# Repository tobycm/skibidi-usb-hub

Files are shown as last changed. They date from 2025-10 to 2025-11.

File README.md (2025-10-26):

# skibidi usb hub - 7-port usb hub with some ethernet and an audio out jack

me when my ethernet port and audio jack is broken and i need more usb A ports :bonk:

features:
 - 1 USB C port for upstream
 - 2 USB C ports
 - 2 USB A ports
 - 2 100M capable Ethernet ports
 - 1 Audio Jack (maybe both line in and line out)

## Build

JLCPCB Params:
- Stack up: JLC04161H-7628

## Pictures:

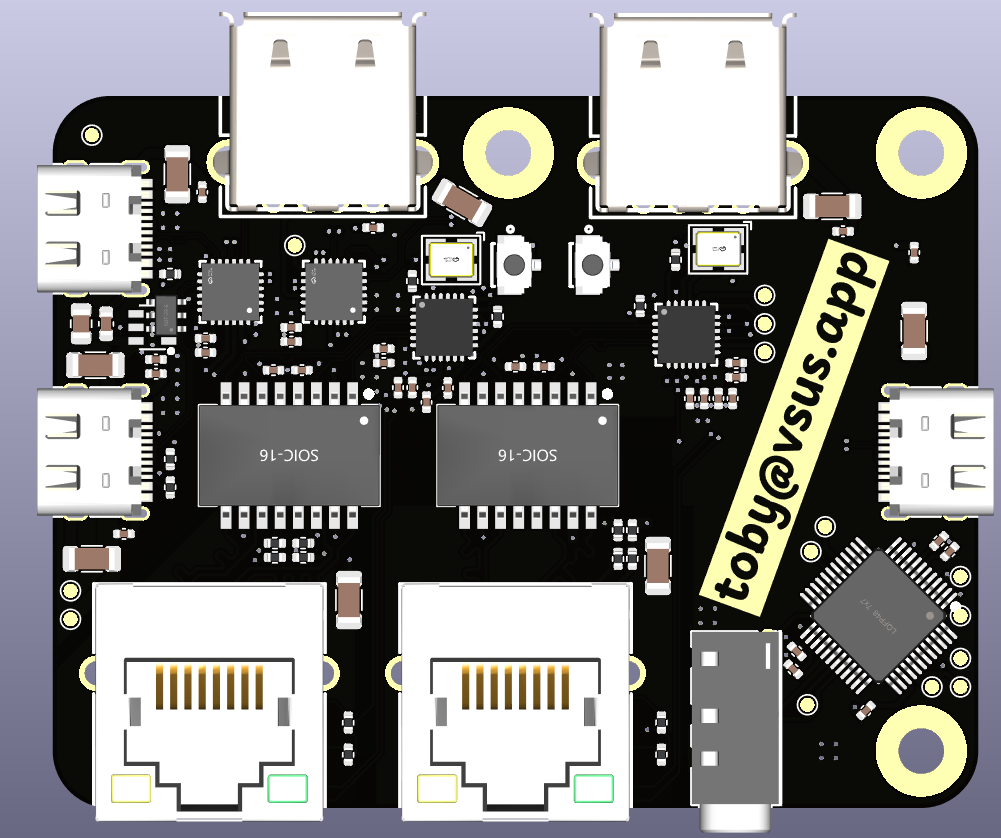
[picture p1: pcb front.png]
pcb front
PCB Front: 

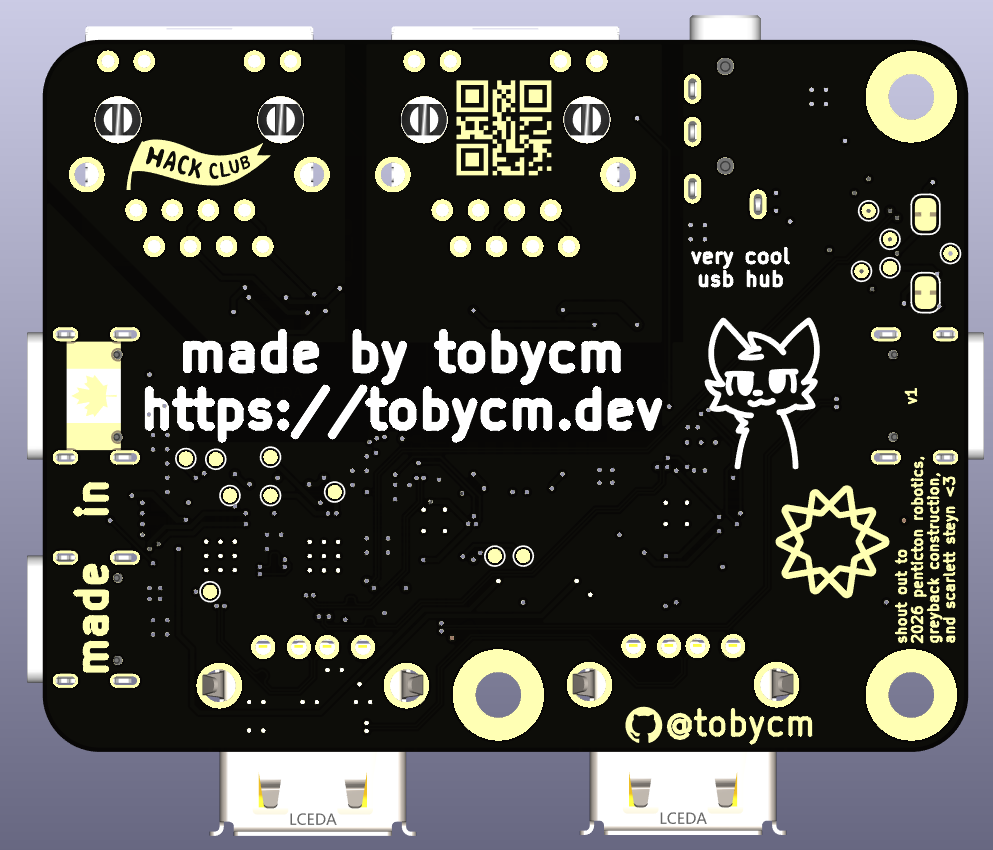
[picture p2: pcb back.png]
pcb back
PCB Back:

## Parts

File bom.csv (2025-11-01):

Qty | Value | LCSC Part #
9 | 100nF | C1525
19 | 1uF | C52923
1 | 10uF | C19702
1 | 47uF | C16780
6 | 100uF | C15008
4 | 10nF | C60133
2 | 1nF | C9196
3 | 56kohm | C25796
2 | 2.49kohm | C25884
2 | 5.1kohm | C25905
8 | 75ohm | C114757
4 | 470ohm | C114877
2 | R-RJ45S08P-C000 | C386764
2 | B3U-1100PM | C6467298
2 | H1102NLT_C20623173 | C20623173
2 | CH334F_C5187527 | C5187527
1 | CH217K | C7462749
3 | GT-USB-7010ASV | C2988369
2 | RTL8152B-VB-CG | C50656
1 | HS-100B | C371351
1 | PJ-320A-4P DIP | C18185602
2 | AF 90° WJDG | C456018
2 | X322516MLB4SI | C13738
 | LCSC | $47.73
 | LCSC Shipping | $20.00
 | PCB | $28.00
 | Stencil | $3.00
 | JLCPCB Shipping | $9.00
 | Shipping customs | $22.69
 | Total | $130.42

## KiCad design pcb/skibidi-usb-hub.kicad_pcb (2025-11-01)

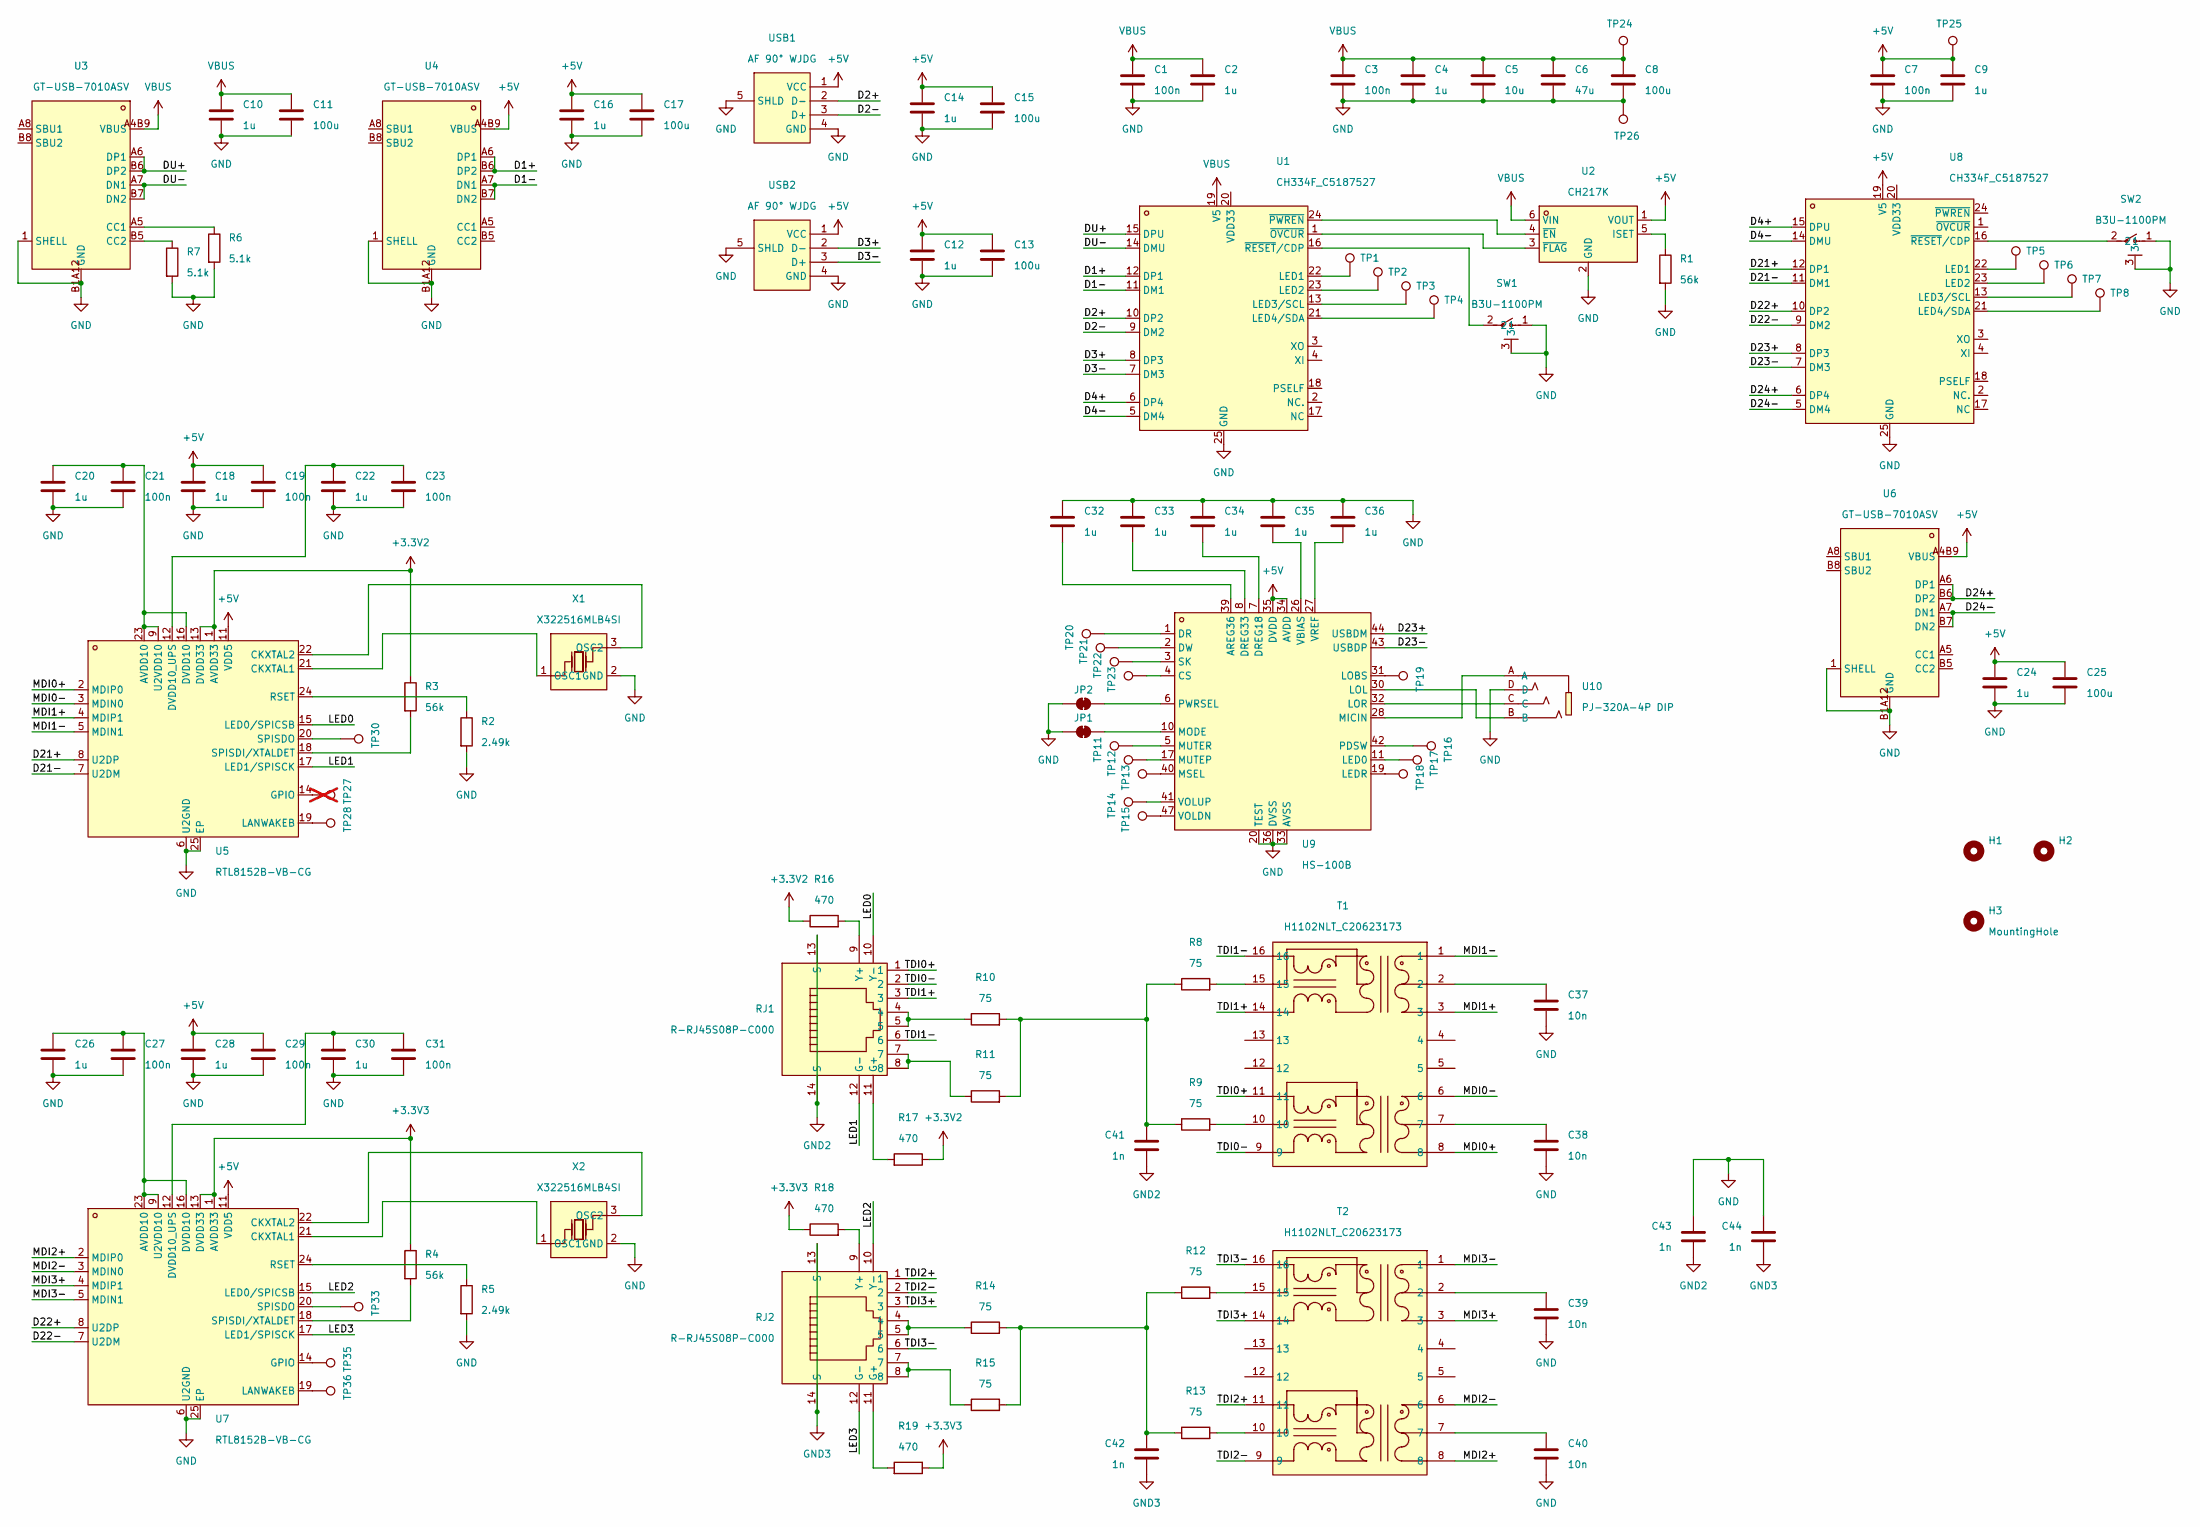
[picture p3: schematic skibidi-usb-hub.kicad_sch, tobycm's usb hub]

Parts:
C1, C3, C7, C19, C21, C23, C27, C29, C31: 100n; C_0402_1005Metric; LCSC Part # C1525
C2, C4, C9, C10, C12, C14, C16, C18, C20, C22, C24, C26, C28, C30, C32, C33, C34, C35, C36: 1u; C_0402_1005Metric; LCSC Part # C52923
C5: 10u; C_0603_1608Metric; LCSC Part # C19702
C6: 47u; C_0805_2012Metric; LCSC Part # C16780
C8, C11, C13, C15, C17, C25: 100u; C_1206_3216Metric; LCSC Part # C15008
C37, C38, C39, C40: 10n; C_0402_1005Metric; LCSC Part # C60133
C41, C42, C43, C44: 1n; C_1206_3216Metric; LCSC Part # C9196
H1, H2, H3: MountingHole; MountingHole_3.2mm_M3_Pad
JP1, JP2: SolderJumper_2_Bridged; SolderJumper-2_P1.3mm_Bridged_RoundedPad1.0x1.5mm
R1, R3, R4: 56k; R_0402_1005Metric; LCSC Part # C25796
R2, R5: 2.49k; R_0402_1005Metric; LCSC Part # C25884
R6, R7: 5.1k; R_0402_1005Metric; LCSC Part # C25905
R8, R9, R10, R11, R12, R13, R14, R15: 75; R_0402_1005Metric; LCSC Part # C114757
R16, R17, R18, R19: 470; R_0402_1005Metric; LCSC Part # C114877
RJ1, RJ2: R-RJ45S08P-C000; RJ45-TH_R-RJ45S08P-C000; LCSC Part C386764
SW1, SW2: B3U-1100PM; SW-SMD_3P-L3.0-W2.5-LS4.0; LCSC Part C6467298
T1, T2: H1102NLT_C20623173; XFMR-SMD_H1102NLT; LCSC Part C20623173
TP1, TP2, TP3, TP4, TP5, TP6, TP7, TP8, TP11, TP12, TP13, TP14, TP15, TP16, TP17, TP18, TP19, TP20, TP21, TP22, TP23, TP24, TP25, TP26, TP28, TP30, TP33, TP35, TP36: TestPoint; TestPoint_Pad_D1.0mm
TP27: TestPoint; TestPoint_Pad_D1.0mm; not fitted
U1, U8: CH334F_C5187527; QFN-24_L4.0-W4.0-P0.50-BL-EP2.8; LCSC Part C5187527
U2: CH217K; SOT-23-6_L2.9-W1.6-P0.95-LS2.8-BL; LCSC Part C7462749
U3, U4, U6: GT-USB-7010ASV; USB-C-SMD_G-SWITCH_GT-USB-7010ASV; LCSC Part C2988369
U5, U7: RTL8152B-VB-CG; QFN-24_L4.0-W4.0-P0.50-BL-EP2.0; LCSC Part C50656
U9: HS-100B; LQFP-48_L7.0-W7.0-P0.50-LS9.0-BL; LCSC Part C371351
U10: PJ-320A-4P DIP; AUDIO-TH_PJ-320A-4P-DIP; LCSC Part C18185602
USB1, USB2: AF 90° WJDG; USB-A-TH_AF-WJDG; LCSC Part C456018
X1, X2: X322516MLB4SI; OSC-SMD_4P-L3.2-W2.5-BL; LCSC Part C13738

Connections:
+3.3V2: R3.1, R16.1, R17.1, U5.1 (AVDD33), U5.10 (AVDD33), U5.13 (DVDD33)
+3.3V3: R4.1, R18.1, R19.1, U7.1 (AVDD33), U7.10 (AVDD33), U7.13 (DVDD33)
+5V: C7.1, C9.1, C12.1, C13.1, C14.1, C15.1, C16.1, C17.1, C18.1, C19.1, C24.1, C25.1, C28.1, C29.1, TP25.1, U2.1 (VOUT), U4.A4B9 (VBUS), U4.B4A9 (VBUS), U5.11 (VDD5), U6.A4B9 (VBUS), U6.B4A9 (VBUS), U7.11 (VDD5), U8.19 (V5), U9.29 (AVDD), U9.34 (AVDD), U9.35 (DVDD), USB1.1 (VCC), USB2.1 (VCC)
/D1+: U1.12 (DP1), U4.A6 (DP1), U4.B6 (DP2)
/D1-: U1.11 (DM1), U4.A7 (DN1), U4.B7 (DN2)
/D2+: U1.10 (DP2), USB1.2 (D-)
/D2-: U1.9 (DM2), USB1.3 (D+)
/D3+: U1.8 (DP3), USB2.2 (D-)
/D3-: U1.7 (DM3), USB2.3 (D+)
/D4+: U1.6 (DP4), U8.15 (DPU)
/D4-: U1.5 (DM4), U8.14 (DMU)
/D21+: U5.8 (U2DP), U8.12 (DP1)
/D21-: U5.7 (U2DM), U8.11 (DM1)
/D22+: U7.8 (U2DP), U8.10 (DP2)
/D22-: U7.7 (U2DM), U8.9 (DM2)
/D23+: U8.8 (DP3), U9.44 (USBDM)
/D23-: U8.7 (DM3), U9.43 (USBDP)
/D24+: U6.A6 (DP1), U6.B6 (DP2), U8.6 (DP4)
/D24-: U6.A7 (DN1), U6.B7 (DN2), U8.5 (DM4)
/DU+: U1.15 (DPU), U3.A6 (DP1), U3.B6 (DP2)
/DU-: U1.14 (DMU), U3.A7 (DN1), U3.B7 (DN2)
/LED0: RJ1.10 (Y-), U5.15 (LED0/SPICSB)
/LED1: RJ1.12 (G-), U5.17 (LED1/SPISCK)
/LED2: RJ2.10 (Y-), U7.15 (LED0/SPICSB)
/LED3: RJ2.12 (G-), U7.17 (LED1/SPISCK)
/MDI0+: T1.8, U5.2 (MDIP0)
/MDI0-: T1.6, U5.3 (MDIN0)
/MDI1+: T1.3, U5.4 (MDIP1)
/MDI1-: T1.1, U5.5 (MDIN1)
/MDI2+: T2.8, U7.2 (MDIP0)
/MDI2-: T2.6, U7.3 (MDIN0)
/MDI3+: T2.3, U7.4 (MDIP1)
/MDI3-: T2.1, U7.5 (MDIN1)
/TDI0+: RJ1.1, T1.11
/TDI0-: RJ1.2, T1.9
/TDI1+: RJ1.3, T1.14
/TDI1-: RJ1.6, T1.16
/TDI2+: RJ2.1, T2.11
/TDI2-: RJ2.2, T2.9
/TDI3+: RJ2.3, T2.14
/TDI3-: RJ2.6, T2.16
GND: C1.2, C2.2, C3.2, C4.2, C5.2, C6.2, C7.2, C8.2, C9.2, C10.2, C11.2, C12.2, C13.2, C14.2, C15.2, C16.2, C17.2, C18.2, C19.2, C20.2, C21.2, C22.2, C23.2, C24.2, C25.2, C26.2, C27.2, C28.2, C29.2, C30.2, C31.2, C32.1, C33.1, C34.1, C35.1, C36.1, C37.2, C38.2, C39.2, C40.2, C43.1, C44.1, JP1.1 (A), JP2.1 (A), R1.2, R2.2, R5.2, R6.2, R7.2, SW1.1, SW1.3, SW2.1, SW2.3, TP26.1, U1.25 (GND), U2.2 (GND), U3.1 (SHELL), U3.2 (SHELL), U3.3 (SHELL), U3.4 (SHELL), U3.A1B12 (GND), U3.B1A12 (GND), U4.1 (SHELL), U4.2 (SHELL), U4.3 (SHELL), U4.4 (SHELL), U4.A1B12 (GND), U4.B1A12 (GND), U5.6 (U2GND), U5.25 (EP), U6.1 (SHELL), U6.2 (SHELL), U6.3 (SHELL), U6.4 (SHELL), U6.A1B12 (GND), U6.B1A12 (GND), U7.6 (U2GND), U7.25 (EP), U8.25 (GND), U9.12 (DVSS), U9.20 (TEST), U9.25 (AVSS), U9.33 (AVSS), U9.36 (DVSS), U10.D, USB1.4 (GND), USB1.5 (SHLD), USB2.4 (GND), USB2.5 (SHLD), X1.2 (GND), X1.4 (GND), X2.2 (GND), X2.4 (GND)
GND2: C41.2, C43.2, RJ1.13 (S), RJ1.14 (S)
GND3: C42.2, C44.2, RJ2.13 (S), RJ2.14 (S)
unnamed: C37.1, T1.2
unnamed: C38.1, T1.7
unnamed: C39.1, T2.2
unnamed: C40.1, T2.7
unnamed: C41.1, R8.1, R9.1, R10.2, R11.2
unnamed: C42.1, R12.1, R13.1, R14.2, R15.2
unnamed: JP1.2 (B), U9.10 (MODE)
unnamed: JP2.2 (B), U9.6 (PWRSEL)
unnamed: R8.2, T1.15
unnamed: R9.2, T1.10
unnamed: R10.1, RJ1.4, RJ1.5
unnamed: R11.1, RJ1.7, RJ1.8
unnamed: R12.2, T2.15
unnamed: R13.2, T2.10
unnamed: R14.1, RJ2.4, RJ2.5
unnamed: R15.1, RJ2.7, RJ2.8
unnamed: R17.2, RJ1.11 (G+)
unnamed: R16.2, RJ1.9 (Y+)
unnamed: R19.2, RJ2.11 (G+)
unnamed: R18.2, RJ2.9 (Y+)
unnamed: TP1.1, U1.22 (LED1)
unnamed: TP2.1, U1.23 (LED2)
unnamed: TP3.1, U1.13 (LED3/SCL)
unnamed: TP4.1, U1.21 (LED4/SDA)
unnamed: U1.1 (~OVCUR), U2.3 (~FLAG)
unnamed: U1.24 (~PWREN), U2.4 (~EN)
unnamed: SW1.2, U1.16 (~RESET/CDP)
unnamed: R1.1, U2.5 (ISET)
unnamed: R6.1, U3.A5 (CC1)
unnamed: R7.1, U3.B5 (CC2)
unnamed: C20.1, C21.1, U5.9 (U2VDD10), U5.16 (DVDD10), U5.23 (AVDD10)
unnamed: U5.21 (CKXTAL1), X1.1 (OSC1)
unnamed: U5.22 (CKXTAL2), X1.3 (OSC2)
unnamed: C22.1, C23.1, U5.12 (DVDD10_UPS)
unnamed: TP27.1, U5.14 (GPIO)
unnamed: TP28.1, U5.19 (LANWAKEB)
unnamed: R2.1, U5.24 (RSET)
unnamed: R3.2, U5.18 (SPISDI/XTALDET)
unnamed: TP30.1, U5.20 (SPISDO)
unnamed: C26.1, C27.1, U7.9 (U2VDD10), U7.16 (DVDD10), U7.23 (AVDD10)
unnamed: U7.21 (CKXTAL1), X2.1 (OSC1)
unnamed: U7.22 (CKXTAL2), X2.3 (OSC2)
unnamed: C30.1, C31.1, U7.12 (DVDD10_UPS)
unnamed: TP35.1, U7.14 (GPIO)
unnamed: TP36.1, U7.19 (LANWAKEB)
unnamed: R5.1, U7.24 (RSET)
unnamed: R4.2, U7.18 (SPISDI/XTALDET)
unnamed: TP33.1, U7.20 (SPISDO)
unnamed: TP5.1, U8.22 (LED1)
unnamed: TP6.1, U8.23 (LED2)
unnamed: TP7.1, U8.13 (LED3/SCL)
unnamed: TP8.1, U8.21 (LED4/SDA)
unnamed: SW2.2, U8.16 (~RESET/CDP)
unnamed: C32.2, U9.39 (AREG36)
unnamed: TP23.1, U9.4 (CS)
unnamed: TP20.1, U9.1 (DR)
unnamed: C34.2, U9.7 (DREG18)
unnamed: C33.2, U9.8 (DREG33)
unnamed: TP21.1, U9.2 (DW)
unnamed: TP17.1, U9.11 (LED0)
unnamed: TP18.1, U9.19 (LEDR)
unnamed: TP19.1, U9.31 (LOBS)
unnamed: U9.30 (LOL), U10.B
unnamed: U9.32 (LOR), U10.C
unnamed: U9.28 (MICIN), U10.A
unnamed: TP13.1, U9.40 (MSEL)
unnamed: TP12.1, U9.17 (MUTEP)
unnamed: TP11.1, U9.5 (MUTER)
unnamed: TP16.1, U9.42 (PDSW)
unnamed: TP22.1, U9.3 (SK)
unnamed: C35.2, U9.26 (VBIAS)
unnamed: TP15.1, U9.47 (VOLDN)
unnamed: TP14.1, U9.41 (VOLUP)
unnamed: C36.2, U9.27 (VREF)
VBUS: C1.1, C2.1, C3.1, C4.1, C5.1, C6.1, C8.1, C10.1, C11.1, TP24.1, U1.19 (V5), U2.6 (VIN), U3.A4B9 (VBUS), U3.B4A9 (VBUS)

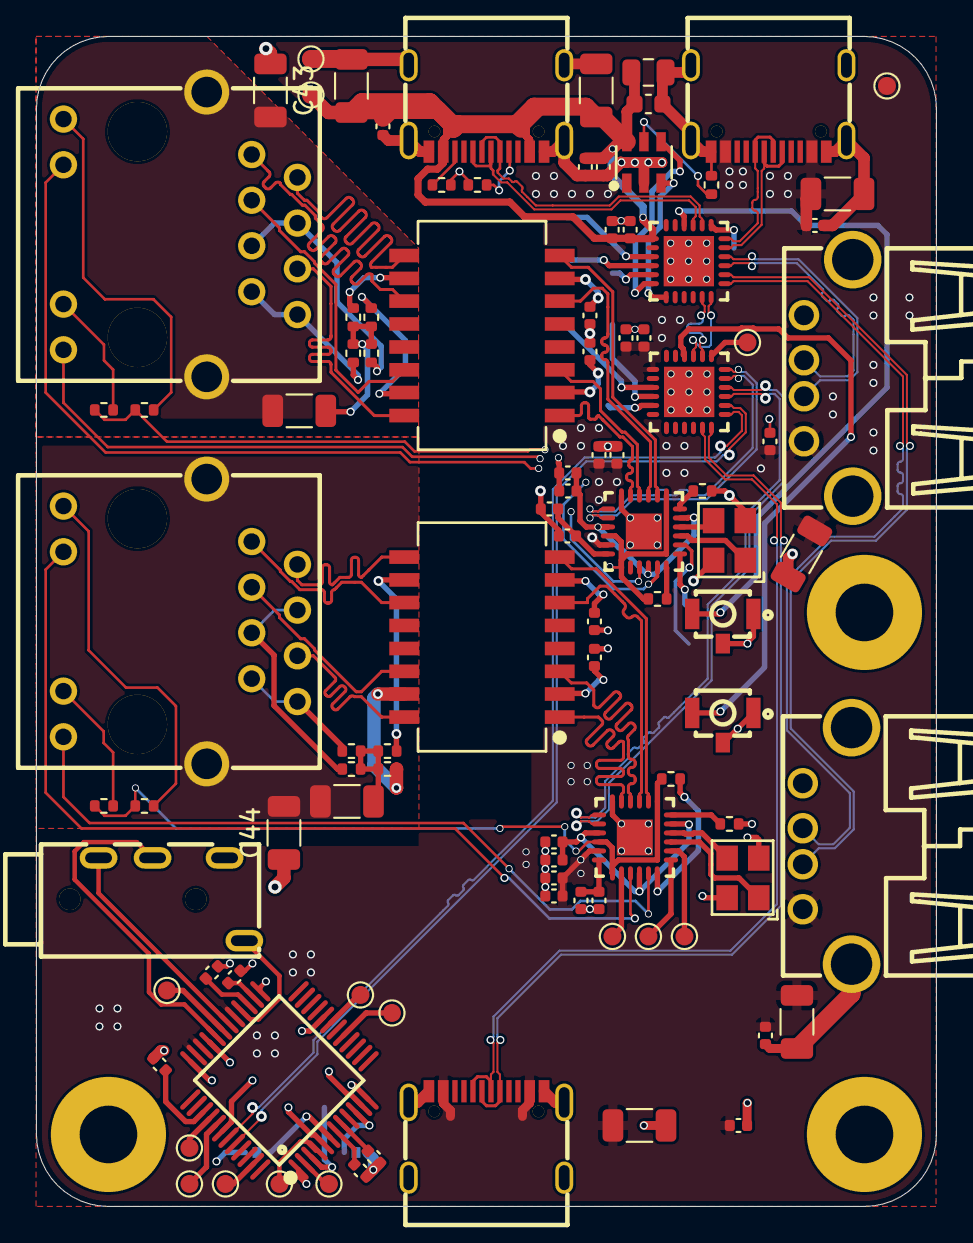
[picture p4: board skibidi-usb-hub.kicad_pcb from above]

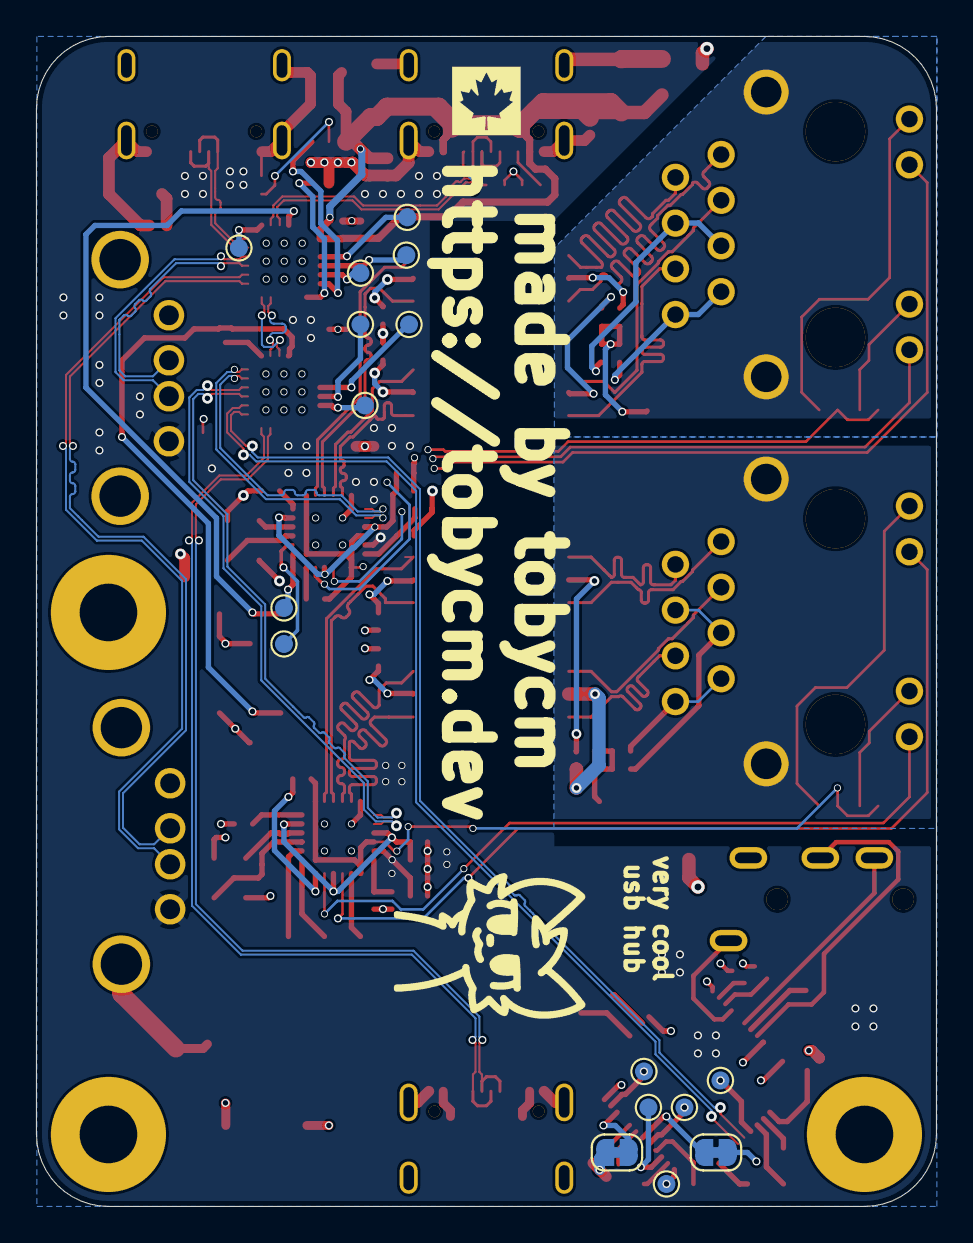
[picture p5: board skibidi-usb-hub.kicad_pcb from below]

Board: 4 copper layers, 50.0 x 65.0 mm, 117 parts (16 on the bottom side), 118 nets.

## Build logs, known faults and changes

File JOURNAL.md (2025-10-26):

<!--
  ===================    !!READ THIS NOTICE!!   ====================
  DO NOT edit this file manually. Your changes WILL BE OVERWRITTEN!
  This journal is auto generated and updated by Hack Club Blueprint.
  To edit this file, please edit your journal entries on Blueprint.
  ==================================================================
-->

## 10/22/2025 6:21 PM - finding usb mux ic  

What I Did

i researched different manufacturers like infineon for their chips.
Next Steps

time to pick all of the parts for the ic to work :D
Issues Faced

the chips i found are usually ball pads and there are so much stuff to route lol. i found a good contender with qfn package for 4 port with integrated usb cc negotiations too :D



## 10/22/2025 6:22 PM - going with the GENESYS GL3523  

What I Did

after some more researching, this part can mux 1 usb port into 4, pretty nice and it doesnt have any pads under the package, which is extra nice
Next Steps

time to make the schematic!



## 10/22/2025 6:22 PM - switching ic to ch334f  

What I Did

nvm im gonna downgrade to usb 2.0 speed, but this chip is so much easier to work with
Next Steps

find other components like usb port protection



## 10/22/2025 6:23 PM - first 3 usb port is done  

What I Did

did the schematic for the first 3 ports, pmic added and usb connectors added, its great
Next Steps

finish the rest of the ports
Issues Faced

some better ics were not available on lcsc :C



## 10/22/2025 6:24 PM - routed all of the necessity for ethernet  

What I Did

did all of the stuff related to usb ethernet
Next Steps

last is audio schematic
Issues Faced

im so tired, next is routing all of the audio stuff



## 10/22/2025 6:25 PM - all done schematic!!!!  

What I Did

schematic is all done, just finished the audio part. pcb layout should be straightforward and easy

Next Steps

pcb layout and fix ethernet wiring



## 10/22/2025 6:25 PM - half way done for pcb routing  

What I Did

did so much routing, was so sick so i couldnt finish it earlier lol
Next Steps

finish the rest of pcb layout
Issues Faced

sick :heavysob: :heavysob:



## 10/23/2025 - routed decoupling capacitors  

did some more pcb routing, decoupling caps some are routed, some still need to be routed.

doubting myself huge times on the ethernet wiring so fixing that



## 10/25/2025 12 AM - routed ethernet and other misc  

routed so much more stuff today, had to use the correct footprint for the rj45 jack so did a lot of fixing, and fixed the wiring for ethernet and the transformer and stuff



## 10/25/2025 10 AM - all components on board yay!  

very likely i will finish this today, only a bunch of testpoints left to route and silkscreen text and art to do, but im close there yayyyyyyyyyyyyyyyy



## 10/25/2025 3 PM - routing done, art done  

pcb routing is finally done, added art

ready to ship, letssssssssssssssssssssssssssssssssssssssssssss goooooooooooooooooooooooooooooooooooooooooooooooo

Screenshot from 2025-10-25 15-52-59

## 10/25/2025 6 PM - sunked some more time fixing diff pairs  

sunked some more time fixing diff pairs

the other stack up has special, so no pcba, but i need pcba

chose a different one, recalculated stuff and rerouted the pairs



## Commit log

2025-09-20 init kicad
    [skibidi-usb-hub.kicad_pcb, skibidi-usb-hub.kicad_sch]
2025-09-21 finished schematic siuuuuu
    [skibidi-usb-hub.kicad_pcb, skibidi-usb-hub.kicad_sch]
2025-10-25 PCB done!!!
    [skibidi-usb-hub.kicad_pcb, skibidi-usb-hub.kicad_sch]
2025-10-26 add bom, update src, add readme
    [bom.csv, skibidi-usb-hub.kicad_pcb, skibidi-usb-hub.kicad_sch]
2025-10-26 update and add pcb step
    [skibidi-usb-hub.kicad_pcb]
2025-11-01 add EMI capacitor for ethernet chassis ground and logic ground
    [skibidi-usb-hub.kicad_pcb, skibidi-usb-hub.kicad_sch]
2025-11-01 update bom without PCBA
    [bom.csv]
